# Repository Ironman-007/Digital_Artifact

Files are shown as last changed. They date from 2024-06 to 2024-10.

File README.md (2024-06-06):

# Digital_Artifact

Input devices:
- mouse encoder: https://www.amazon.com/gp/product/B0CF9FS3QS/ref=ppx_yo_dt_b_asin_title_o00_s00?ie=UTF8&psc=1
- thumb joystick: https://www.adafruit.com/product/5628
- thumbwheel:
  - https://www.mouser.com/ProductDetail/688-SLLB510100
  - https://www.digikey.com/en/products/detail/alps-alpine/RK10J11R0A0L/21721634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
- switch: https://www.amazon.com/TWTADE-Momentary-Assortment-Latching-QC-6X6MM/dp/B0858XRGYW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

MCU:
BC832

IMU:
ICM-20948 (9-DoF)

Actuator:
Linear vibrator

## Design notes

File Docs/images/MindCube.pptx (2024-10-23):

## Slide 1

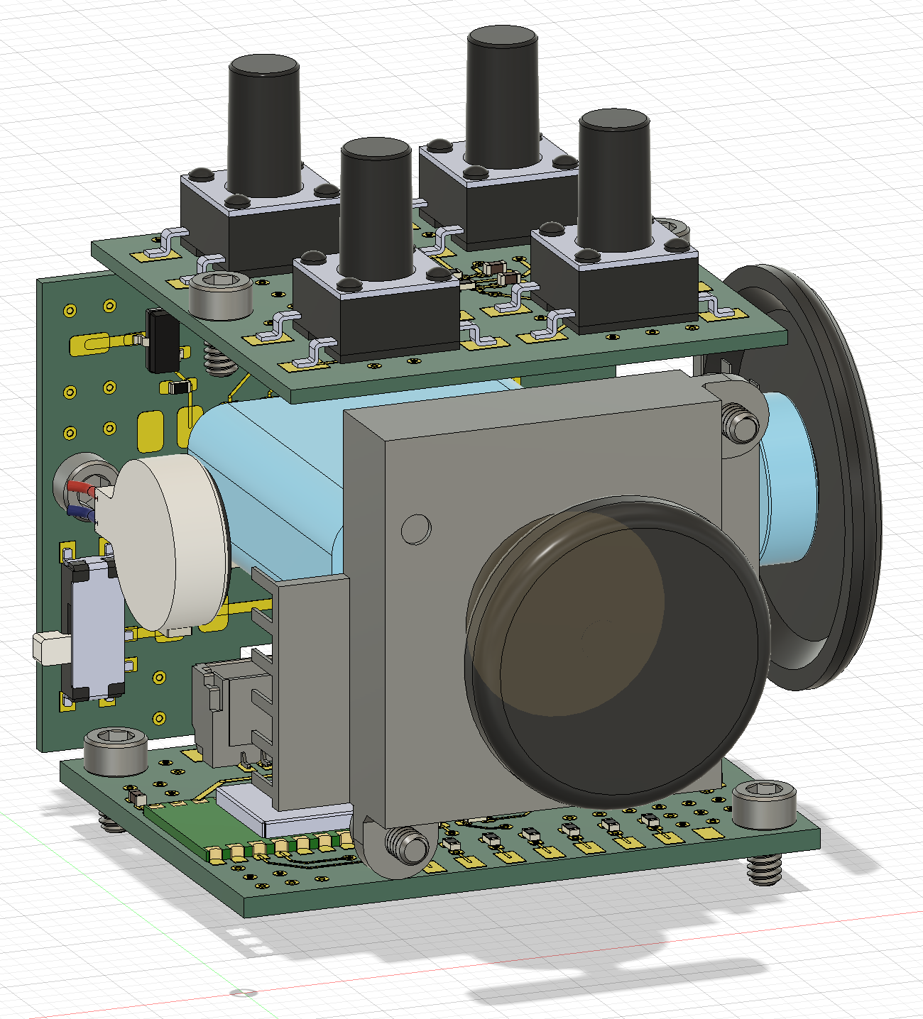
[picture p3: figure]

Button board

Connector board

Ball bearing

100mAh Li-Po

Linear vibration motor

TTC encoder

Joystick

33mm

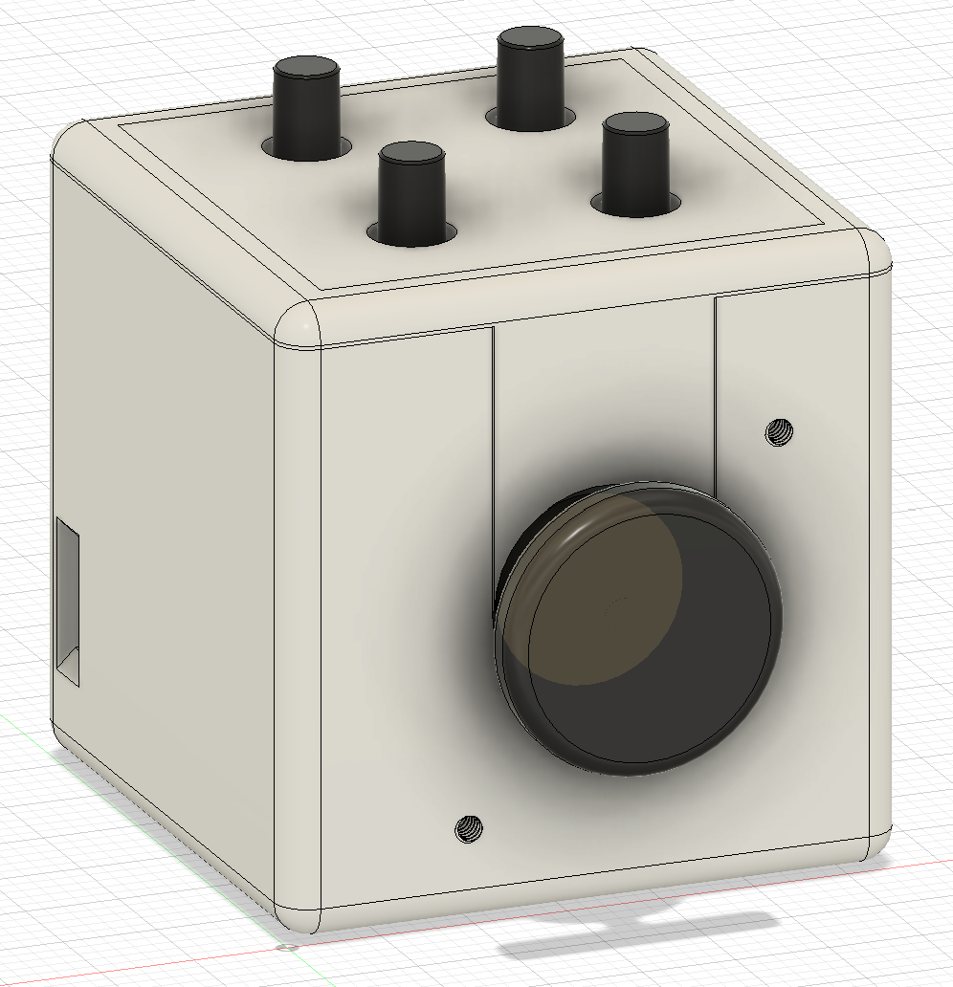
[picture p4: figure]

Main control board

33mm

33mm

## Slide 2

Main control board

Button board

Connector board

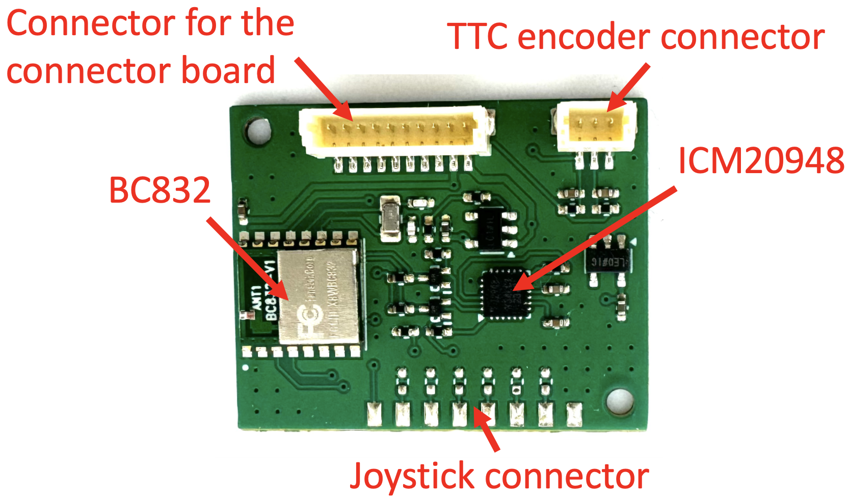
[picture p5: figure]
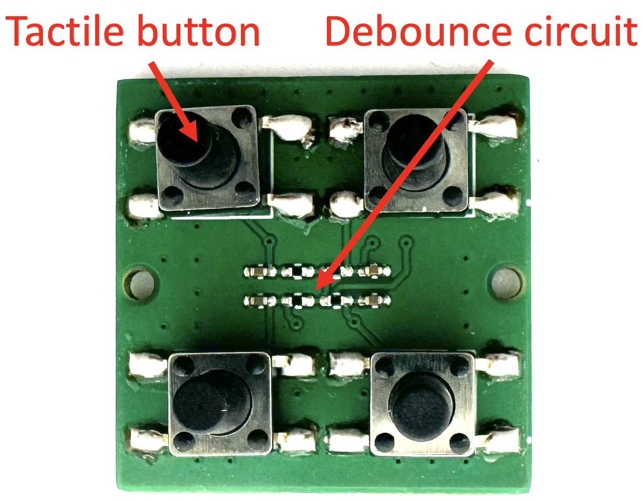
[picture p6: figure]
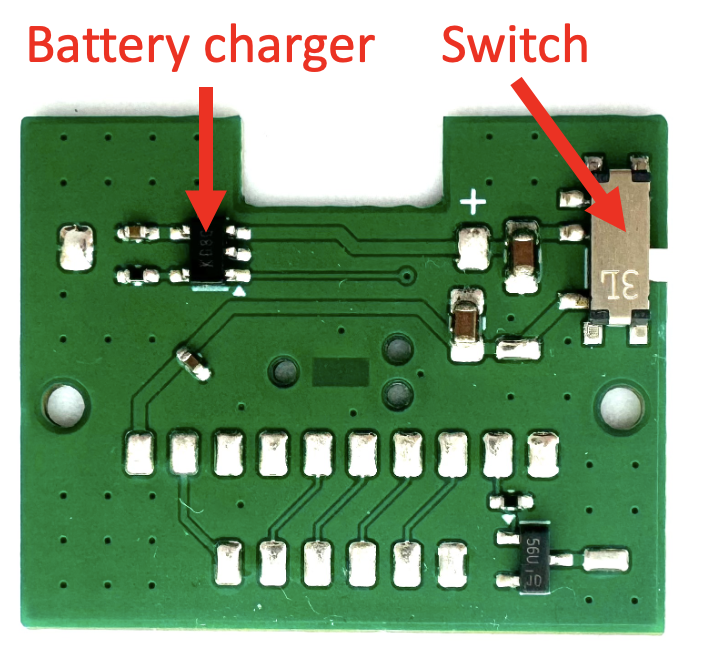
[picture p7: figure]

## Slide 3

Connector for the connector board

TTC encoder connector

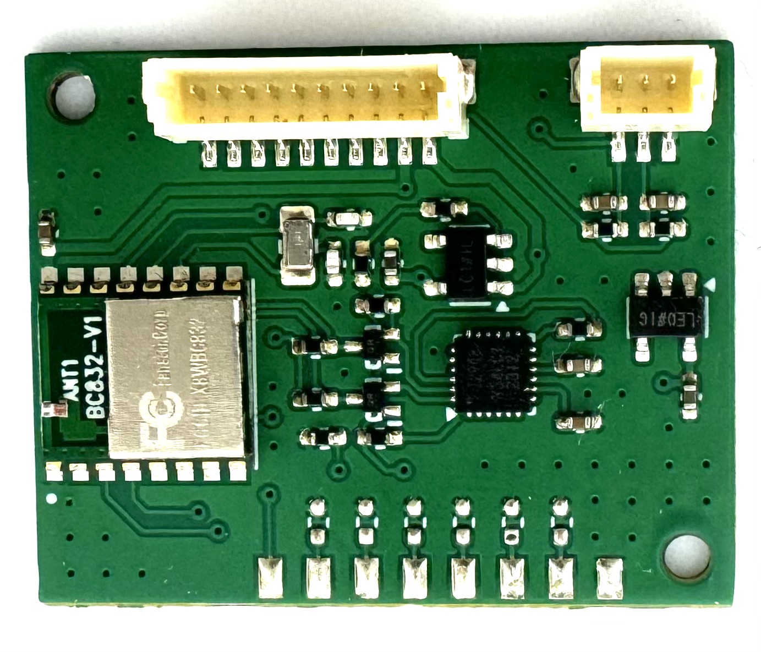
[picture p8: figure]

Joystick connector

ICM20948

BC832

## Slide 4

Tactile button

Debounce circuit

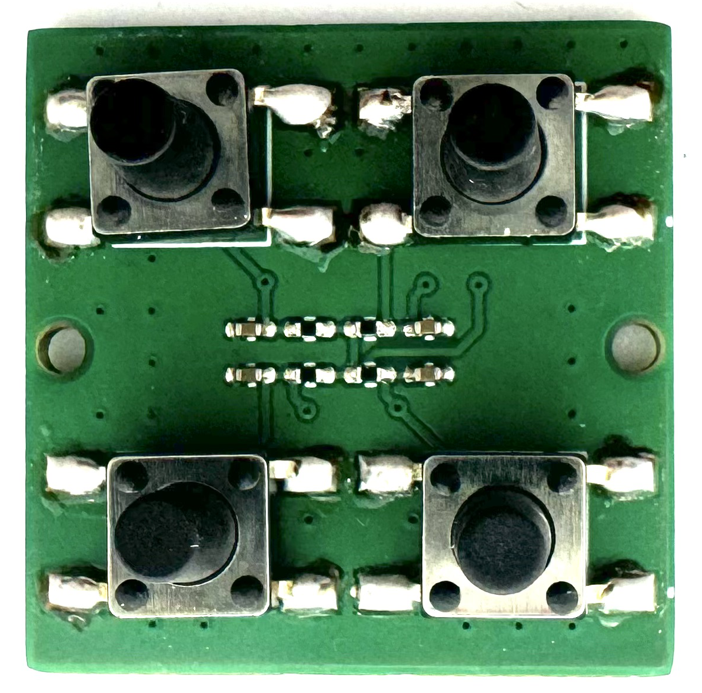
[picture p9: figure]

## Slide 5

Battery charger

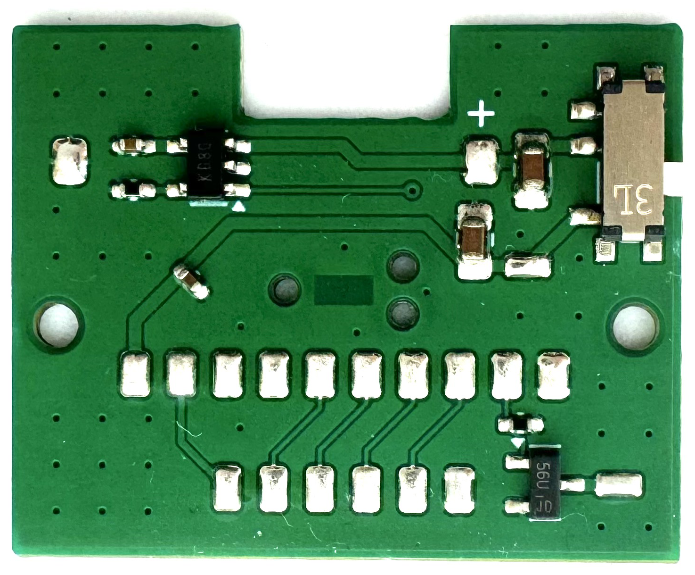
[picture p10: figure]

Switch

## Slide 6

Main control board

Joystick

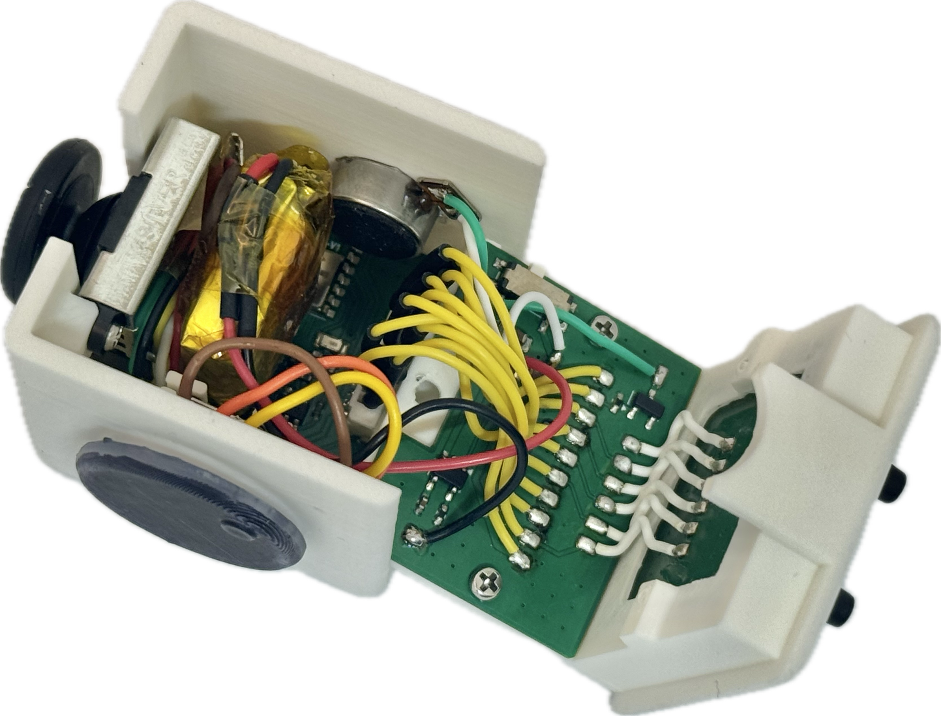
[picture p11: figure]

Linear vibration motor

Connector board

Button board

100mAh LiPo

TTC encoder

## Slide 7

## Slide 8

33mm

33mm

33mm

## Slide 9

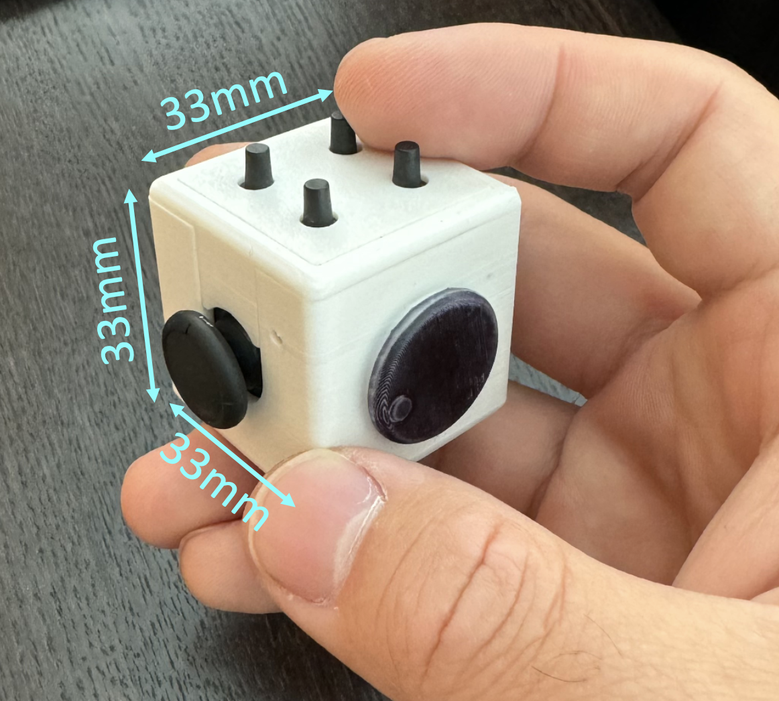
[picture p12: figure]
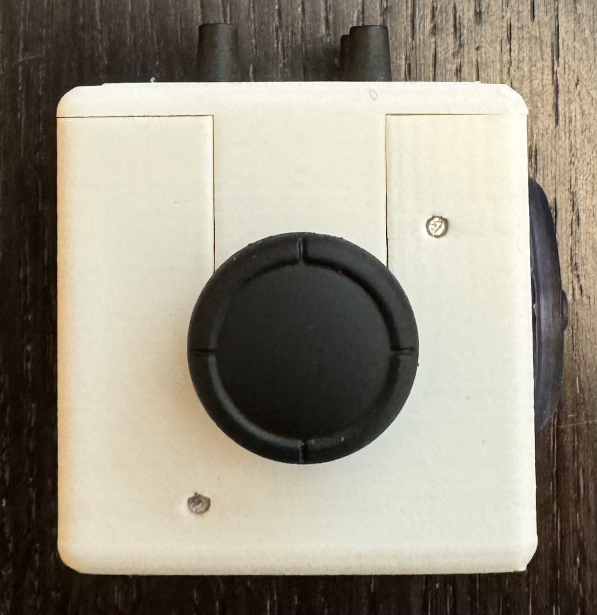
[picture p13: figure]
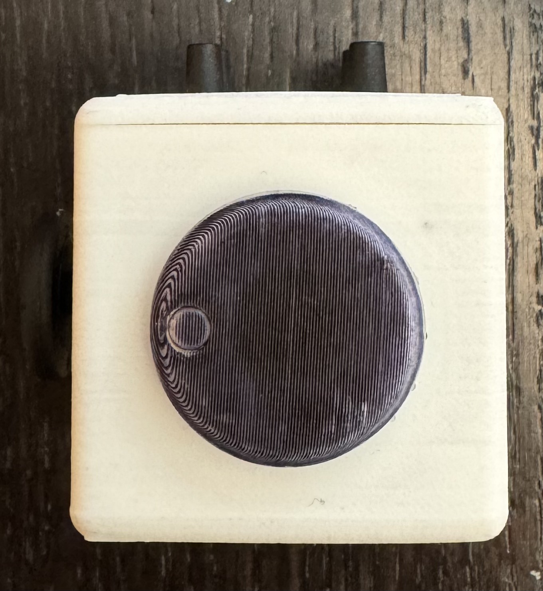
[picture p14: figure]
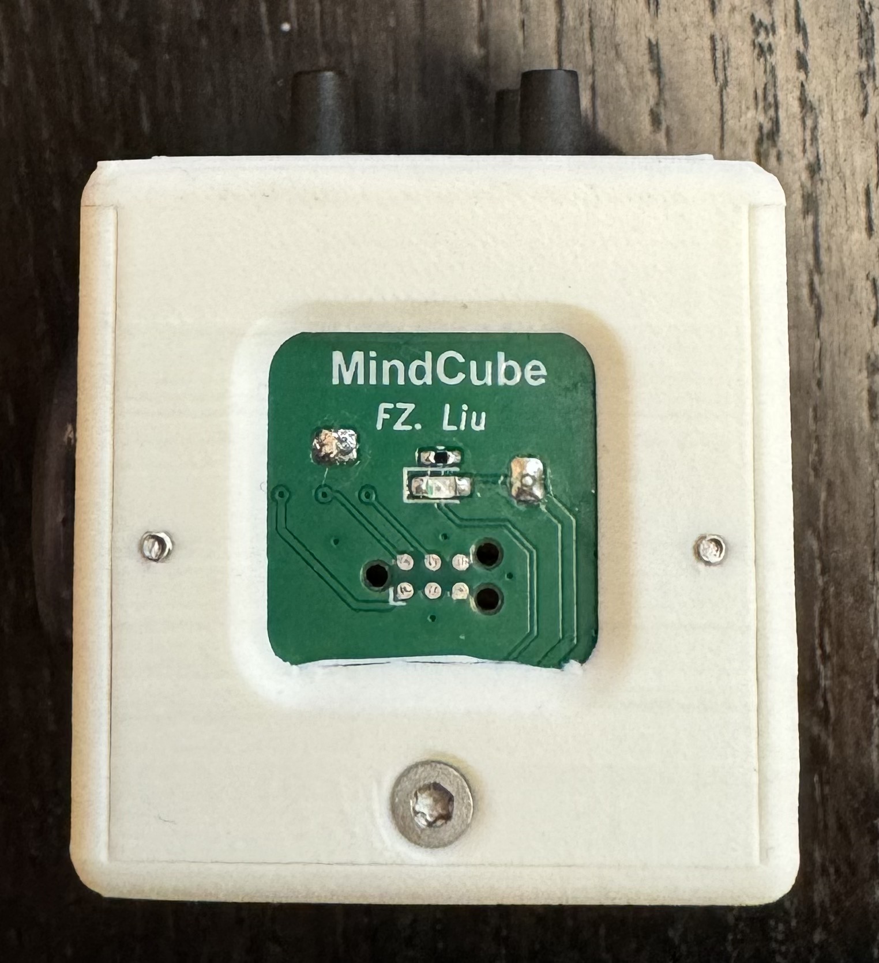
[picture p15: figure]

b

c

d

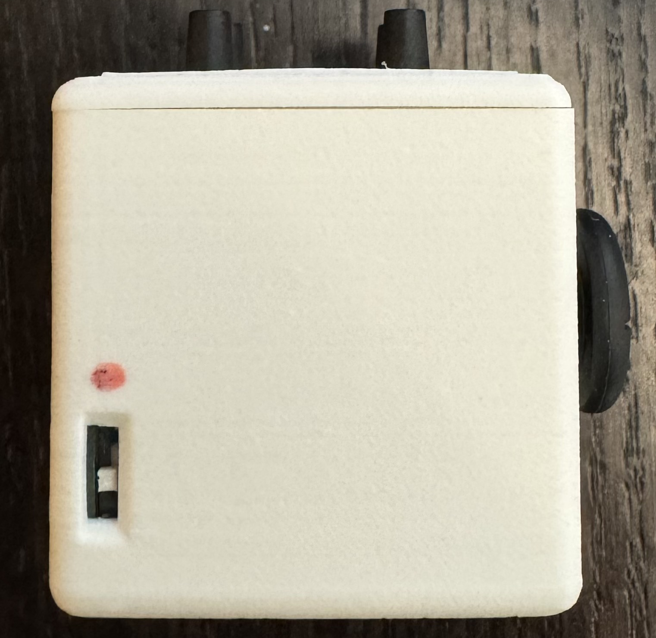
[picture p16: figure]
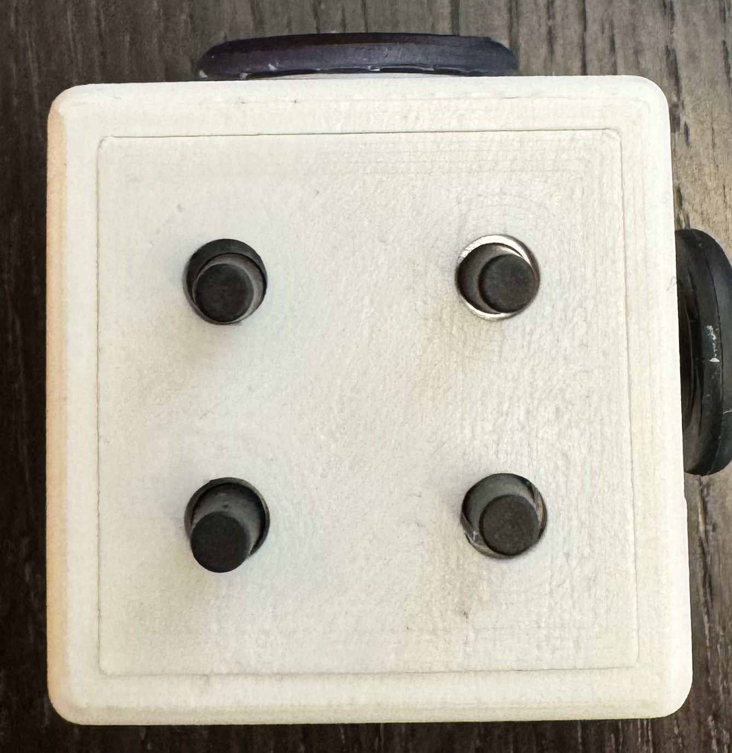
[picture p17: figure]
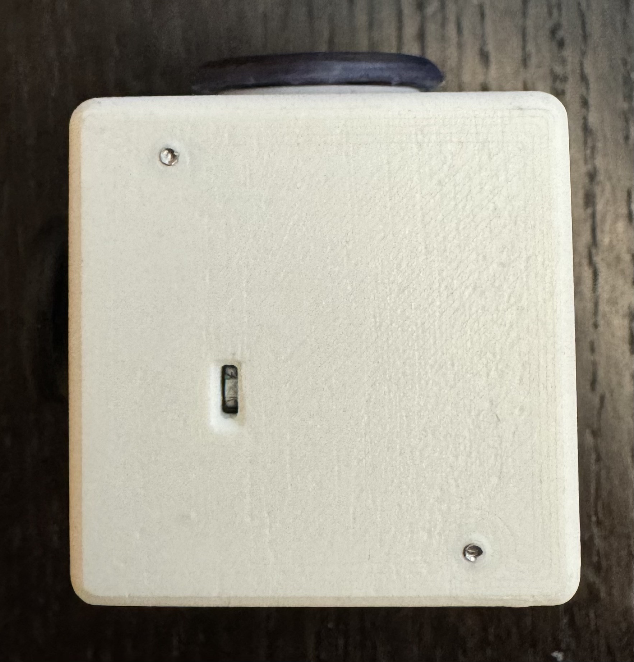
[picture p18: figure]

a

e

f

g

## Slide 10

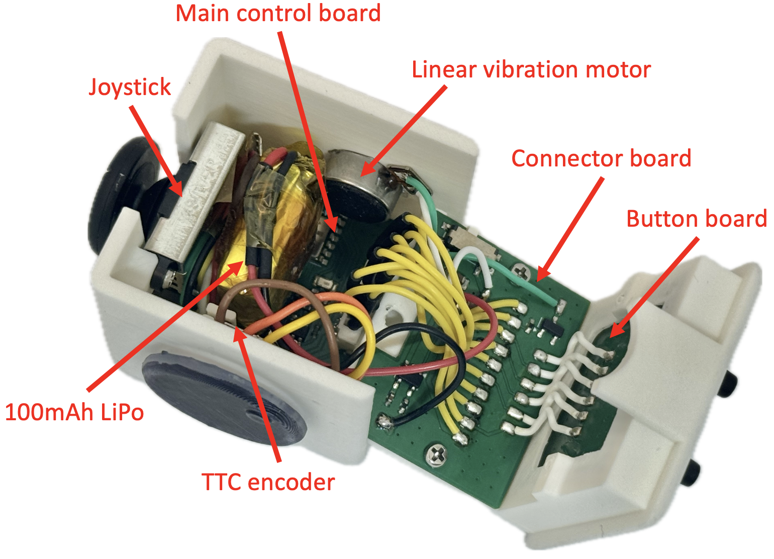
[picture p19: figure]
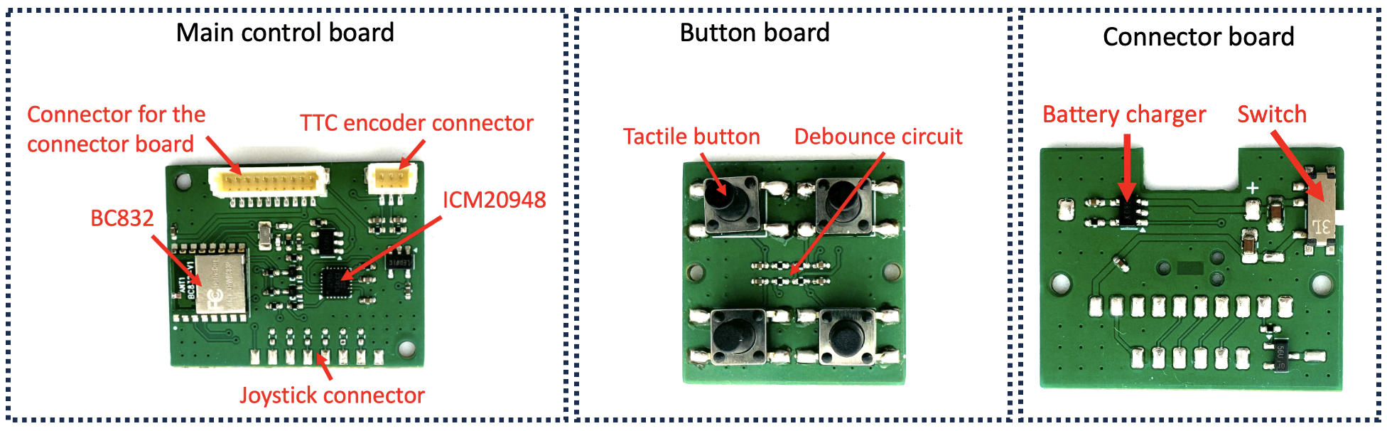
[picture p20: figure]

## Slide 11

Mapping

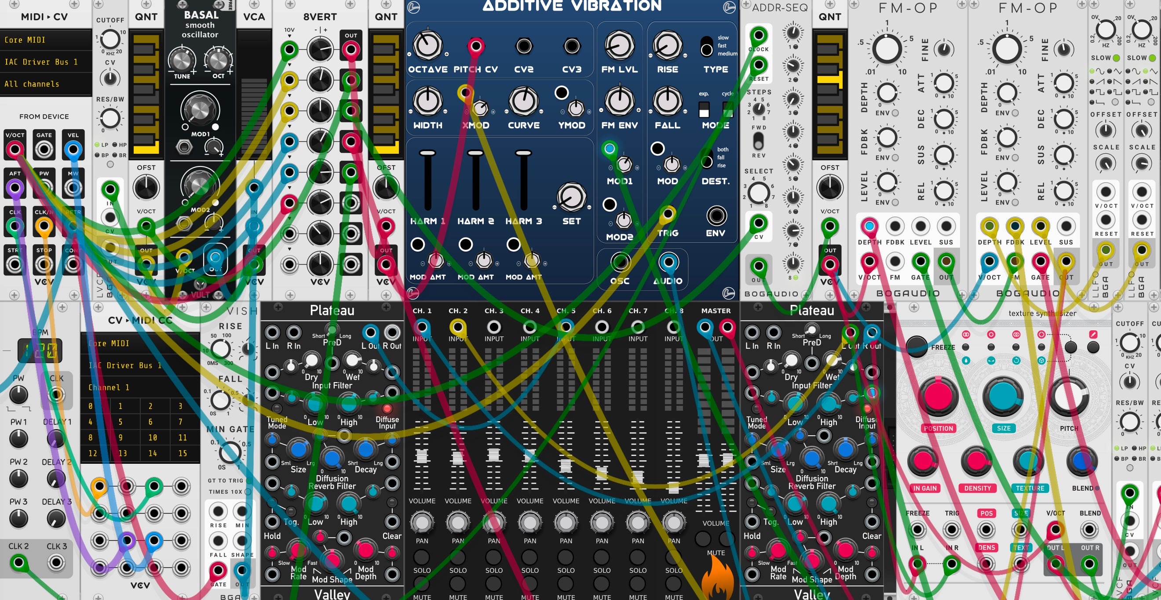
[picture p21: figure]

MIDI

Music

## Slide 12

Neural Network

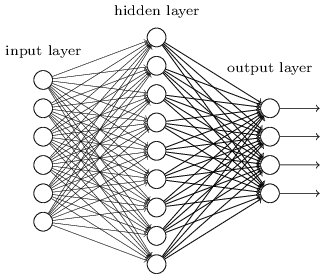
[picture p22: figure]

Focused?

Sensors data

Distracted?

Stressed?

…

Calm?

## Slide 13

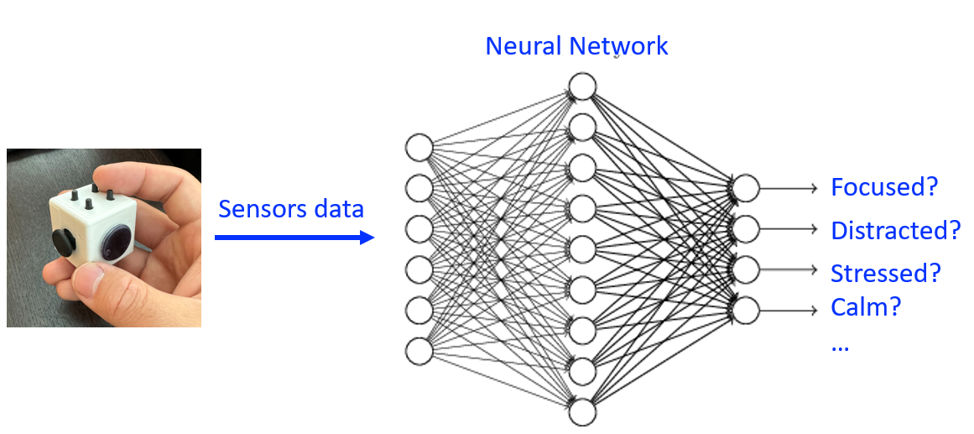
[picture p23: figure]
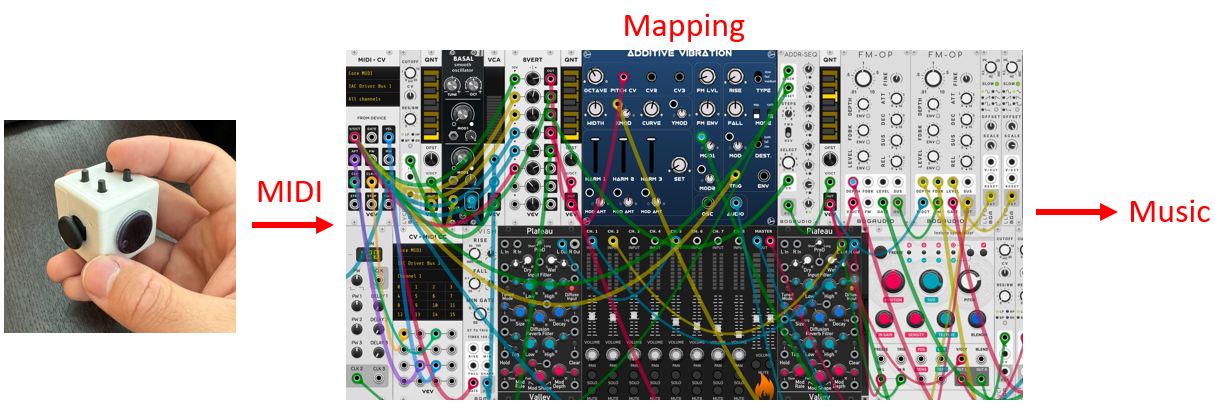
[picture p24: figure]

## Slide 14

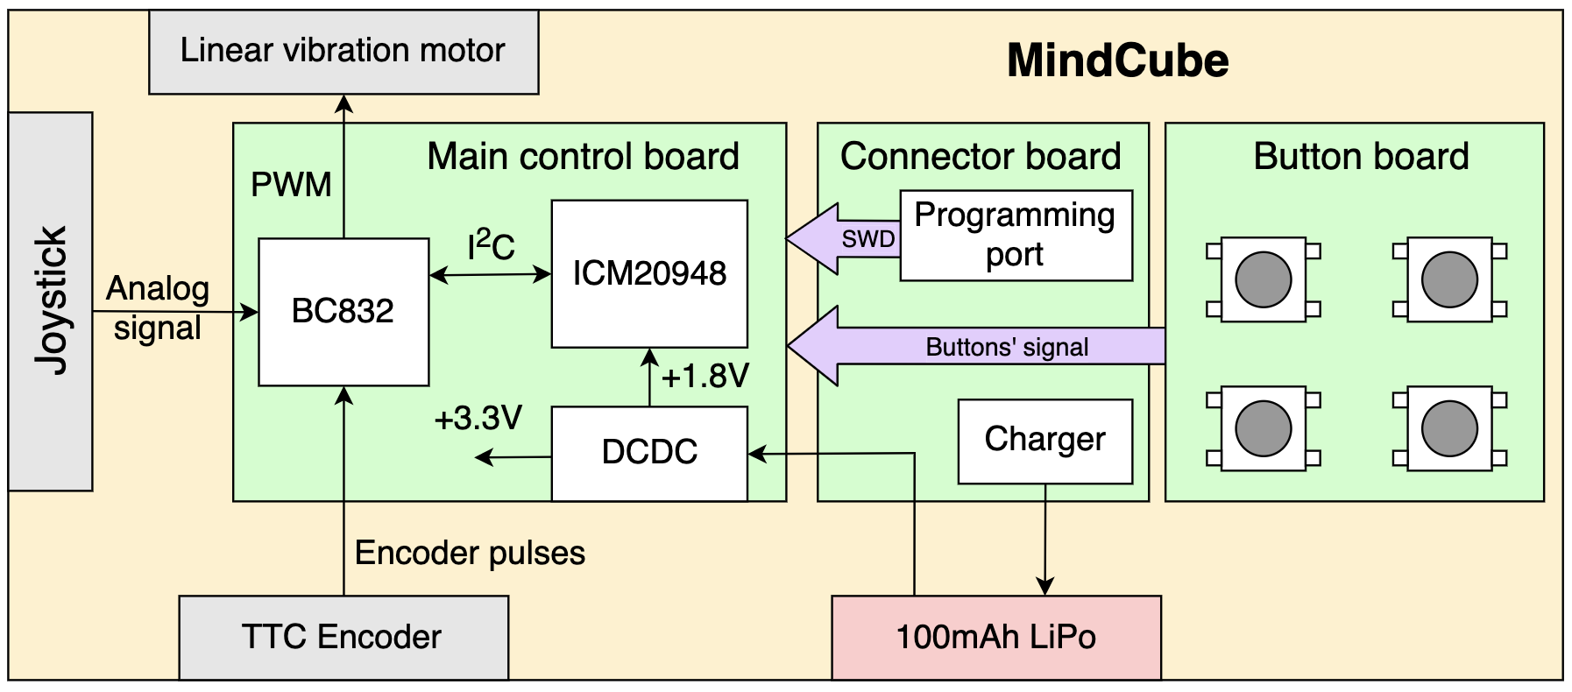
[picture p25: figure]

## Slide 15

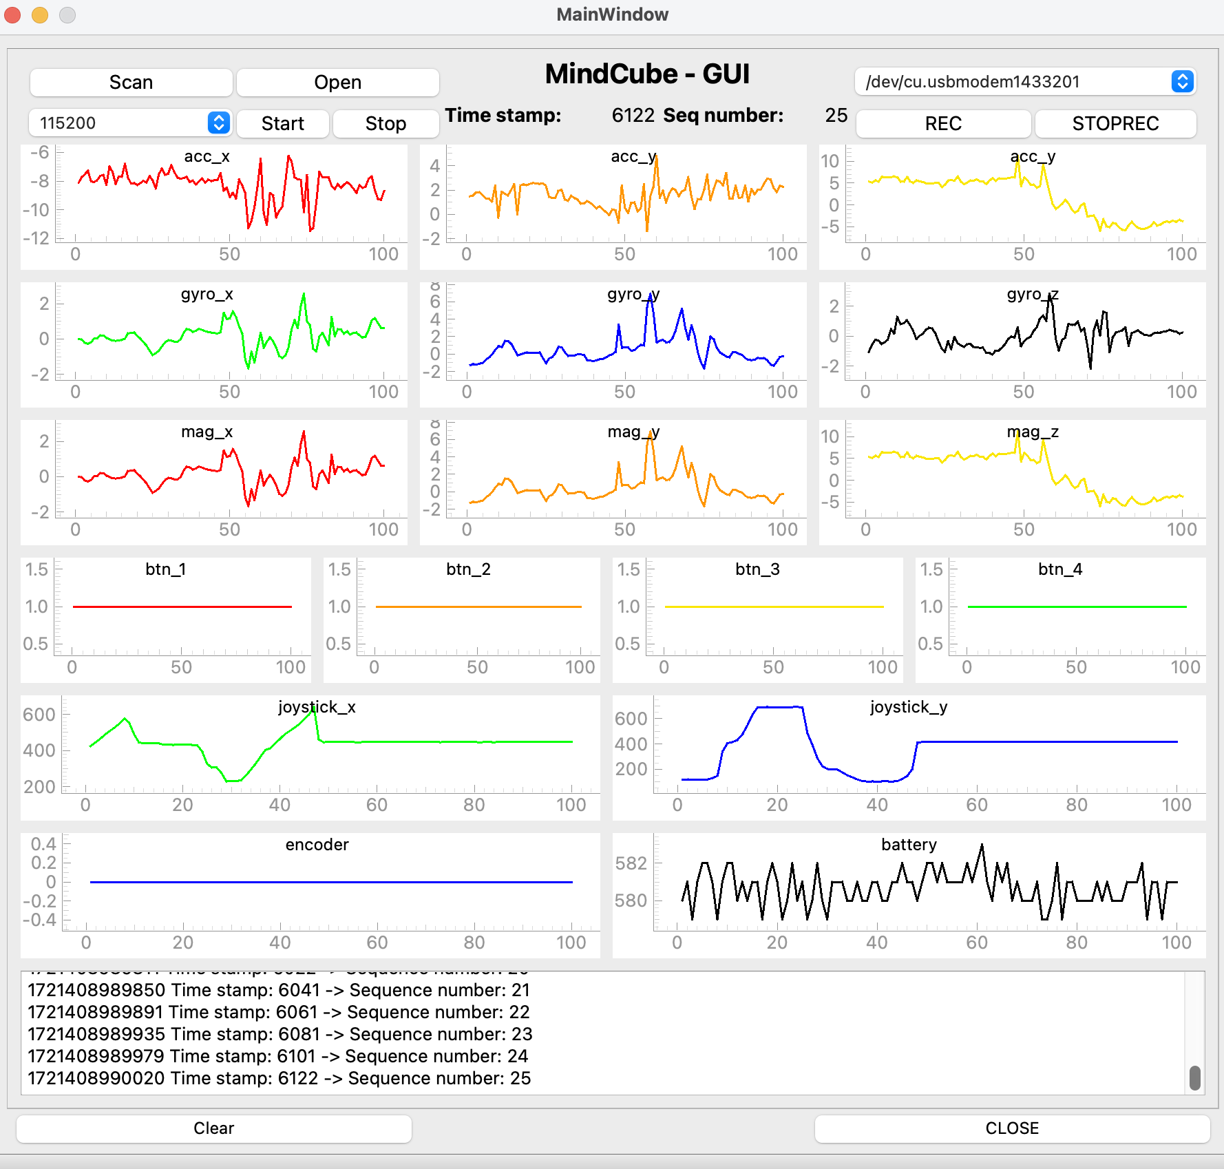
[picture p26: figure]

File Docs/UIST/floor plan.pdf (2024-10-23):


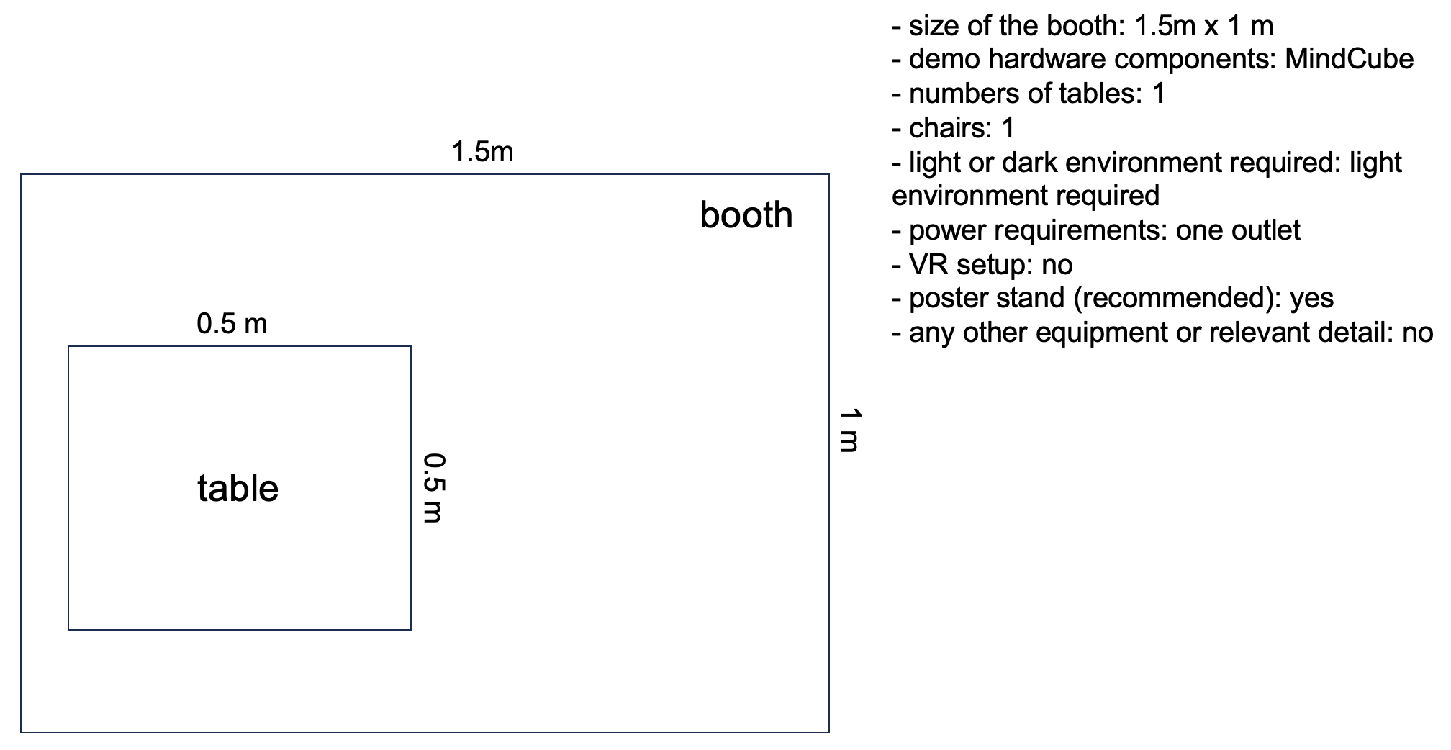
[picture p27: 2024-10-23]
Docs/images/floor plan.png

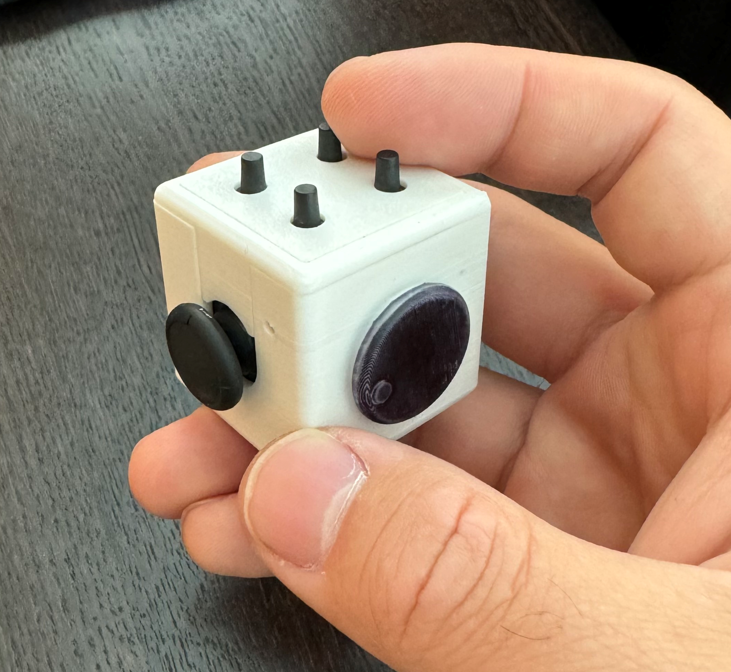
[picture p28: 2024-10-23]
Docs/images/cube.png

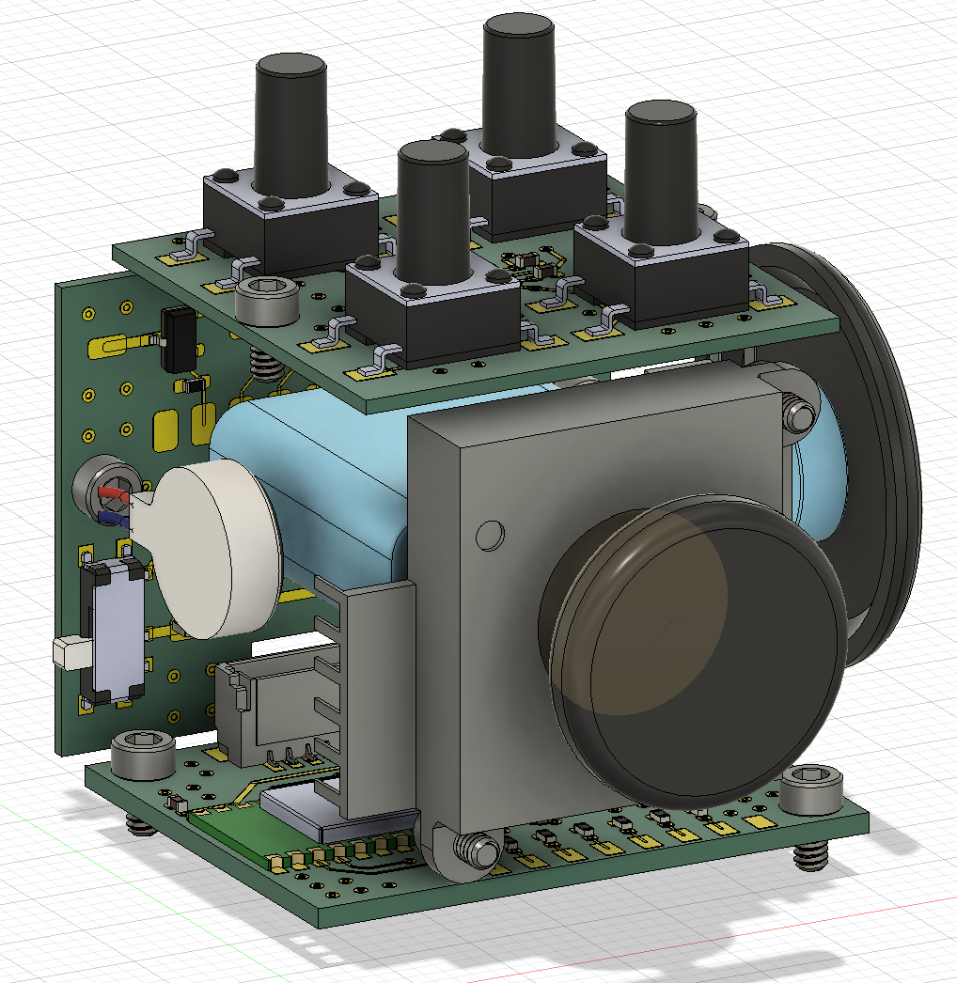
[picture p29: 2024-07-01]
Docs/images/internal.png

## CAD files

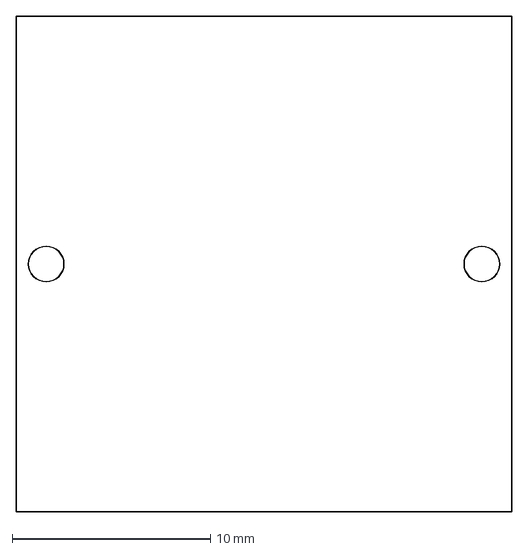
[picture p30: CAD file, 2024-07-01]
PCB/BTN/btn/btn_brd.dxf
25.0 x 25.0 mm

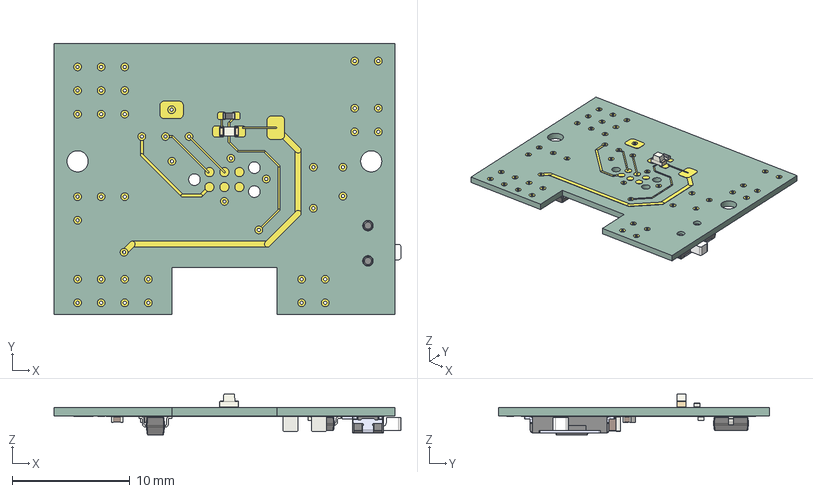
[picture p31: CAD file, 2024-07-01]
PCB/CONN/V1/CONN.step
29.4 x 23.0 x 3.45 mm
R_0402_1005Metric x 3
LED_0603_1608Metric
CUS-12TB
C_0402_1005Metric x 2
SOT_23
SOT_23_5
C_0805_2012Metric x 2
V1_track_1
V1_track_2
V1_track_3
V1_track_4
V1_track_5
V1_track_6
V1_track_7
V1_track_8
V1_track_9
V1_track_10
V1_track_11
V1_track_12
V1_track_13
V1_track_14
V1_track_15
V1_track_16
V1_track_17
V1_track_18
V1_track_19
V1_track_20
V1_track_21
V1_track_22
V1_track_23
V1_track_24
V1_track_25
V1_track_26
V1_track_27
V1_track_28
V1_track_29
V1_track_30
V1_track_31
V1_track_32
V1_track_33
V1_track_34
V1_track_35
V1_track_36
V1_track_37
V1_track_38
V1_track_39
V1_track_40
V1_track_41
V1_track_42
V1_track_43
V1_track_44
V1_track_45
V1_track_46
V1_track_47
V1_track_48
V1_track_49
V1_track_50
V1_track_51
V1_track_52
V1_track_53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

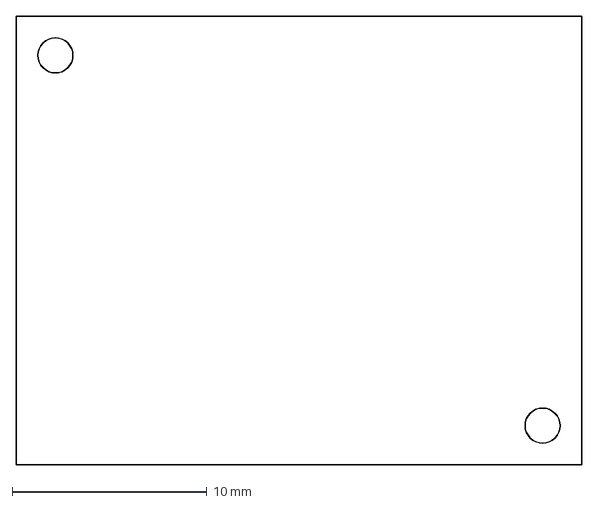
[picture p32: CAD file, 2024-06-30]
PCB/MCU/V1/MCU_board_outline.dxf
29.0 x 23.0 mm

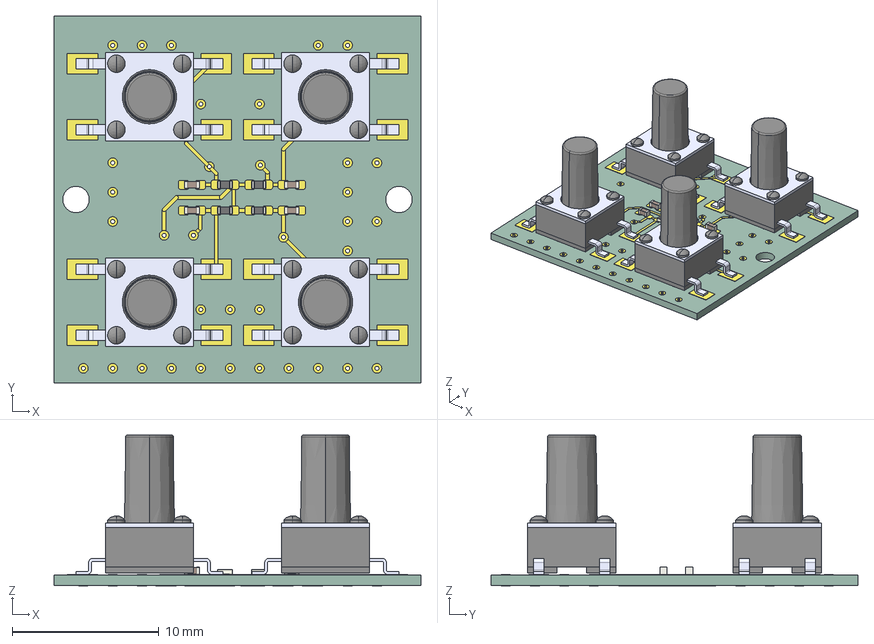
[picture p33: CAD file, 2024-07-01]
PCB/BTN/btn/btn.step
25.0 x 25.0 x 10.3 mm
C_0402_1005Metric x 4
TS04-66-95-BK-100-SMT x 4
R_0402_1005Metric x 4
btn_track_1
btn_track_2
btn_track_3
btn_track_4
btn_track_5
btn_track_6
btn_track_7
btn_track_8
btn_track_9
btn_track_10
btn_track_11
btn_track_12
btn_track_13
btn_track_14
btn_track_15
btn_track_16
btn_track_17
btn_track_18
btn_track_19
btn_track_20
btn_track_21
btn_track_22
btn_track_23
btn_track_24
btn_track_25
btn_track_26
btn_track_27
btn_track_28
btn_track_29
btn_track_30
btn_track_31
btn_track_32
btn_track_33
btn_track_34
btn_track_35
btn_pad_1
btn_pad_2
btn_pad_3
btn_pad_4
btn_pad_5
btn_pad_6
btn_pad_7
btn_pad_8
btn_pad_9
btn_pad_10
btn_pad_11
btn_pad_12
btn_pad_13
btn_pad_14
btn_pad_15
btn_pad_16
btn_pad_17
btn_pad_18
btn_pad_19
btn_pad_20
btn_pad_21
btn_pad_22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

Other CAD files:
PCB/CONN/V1/CONN.dxf

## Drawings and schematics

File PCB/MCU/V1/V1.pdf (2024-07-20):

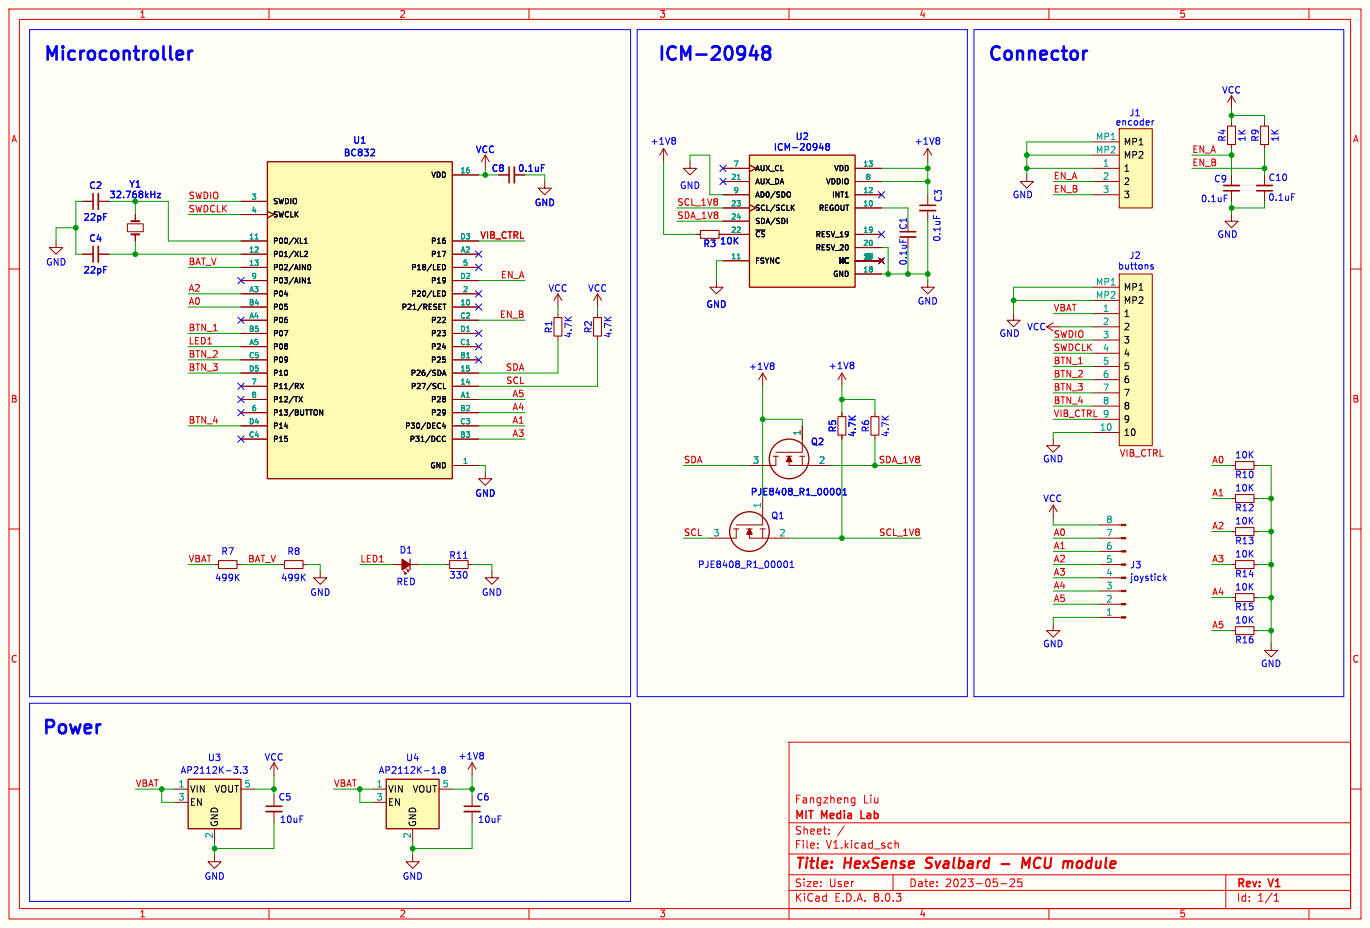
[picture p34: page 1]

Id: 1/1 Title: HexSense Svalbard - MCU module

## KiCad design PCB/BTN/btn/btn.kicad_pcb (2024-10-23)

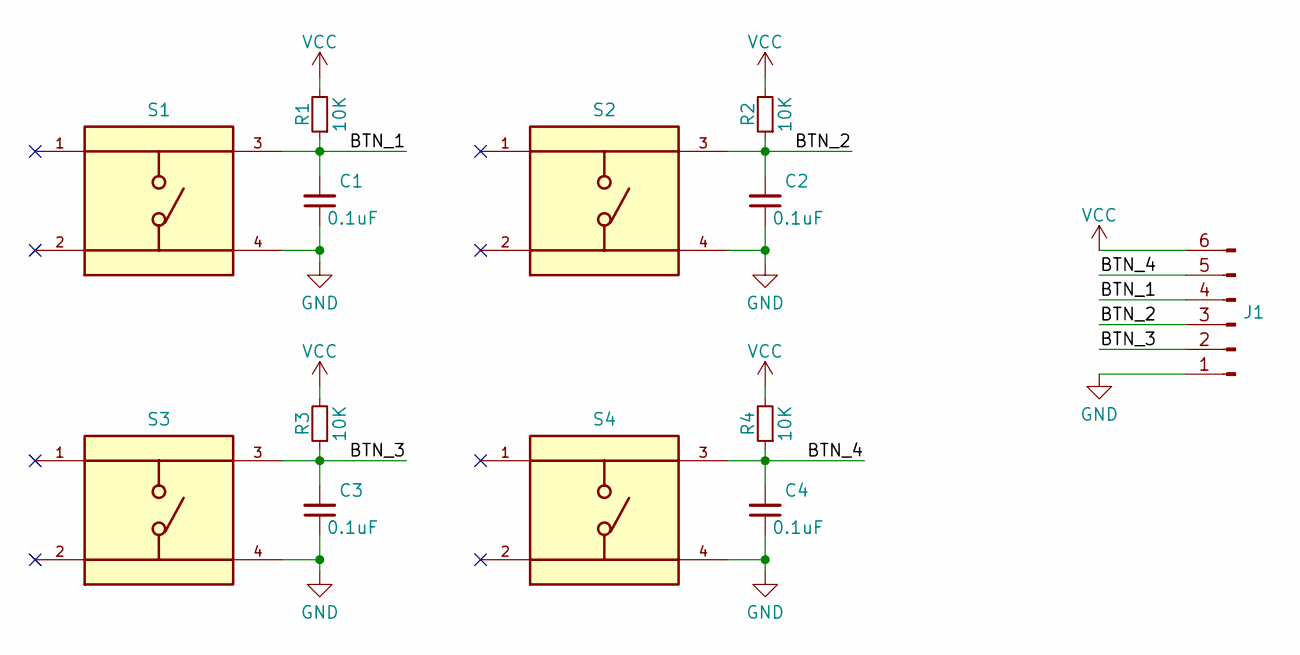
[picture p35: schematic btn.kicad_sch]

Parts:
C1, C2, C3, C4: 0.1uF; C_0402_1005Metric_Pad0.74x0.62mm_HandSolder
J1: Conn_01x06_Pin; Pinheader_2mmx6
R1, R2, R3, R4: 10K; R_0402_1005Metric_Pad0.72x0.64mm_HandSolder
S1, S2, S3, S4: TS04-66-95-BK-100-SMT; SW_TS04-66-95-BK-100-SMT; PARTREV 1.0

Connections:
/BTN_1: C1.2, J1.4, R1.1, S1.3
/BTN_2: C2.2, J1.3, R2.1, S2.3
/BTN_3: C3.2, J1.2, R3.1, S3.3
/BTN_4: C4.2, J1.5, R4.1, S4.3
GND: C1.1, C2.1, C3.1, C4.1, J1.1, S1.4, S2.4, S3.4, S4.4
VCC: J1.6, R1.2, R2.2, R3.2, R4.2

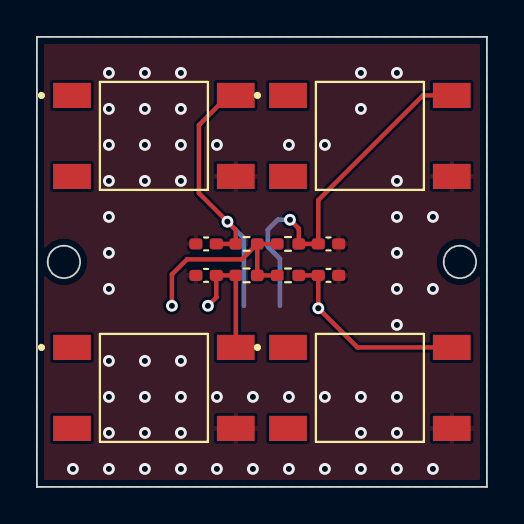
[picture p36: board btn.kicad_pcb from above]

Board: 2 copper layers, 25.0 x 25.0 mm, 13 parts (1 on the bottom side), 6 nets.

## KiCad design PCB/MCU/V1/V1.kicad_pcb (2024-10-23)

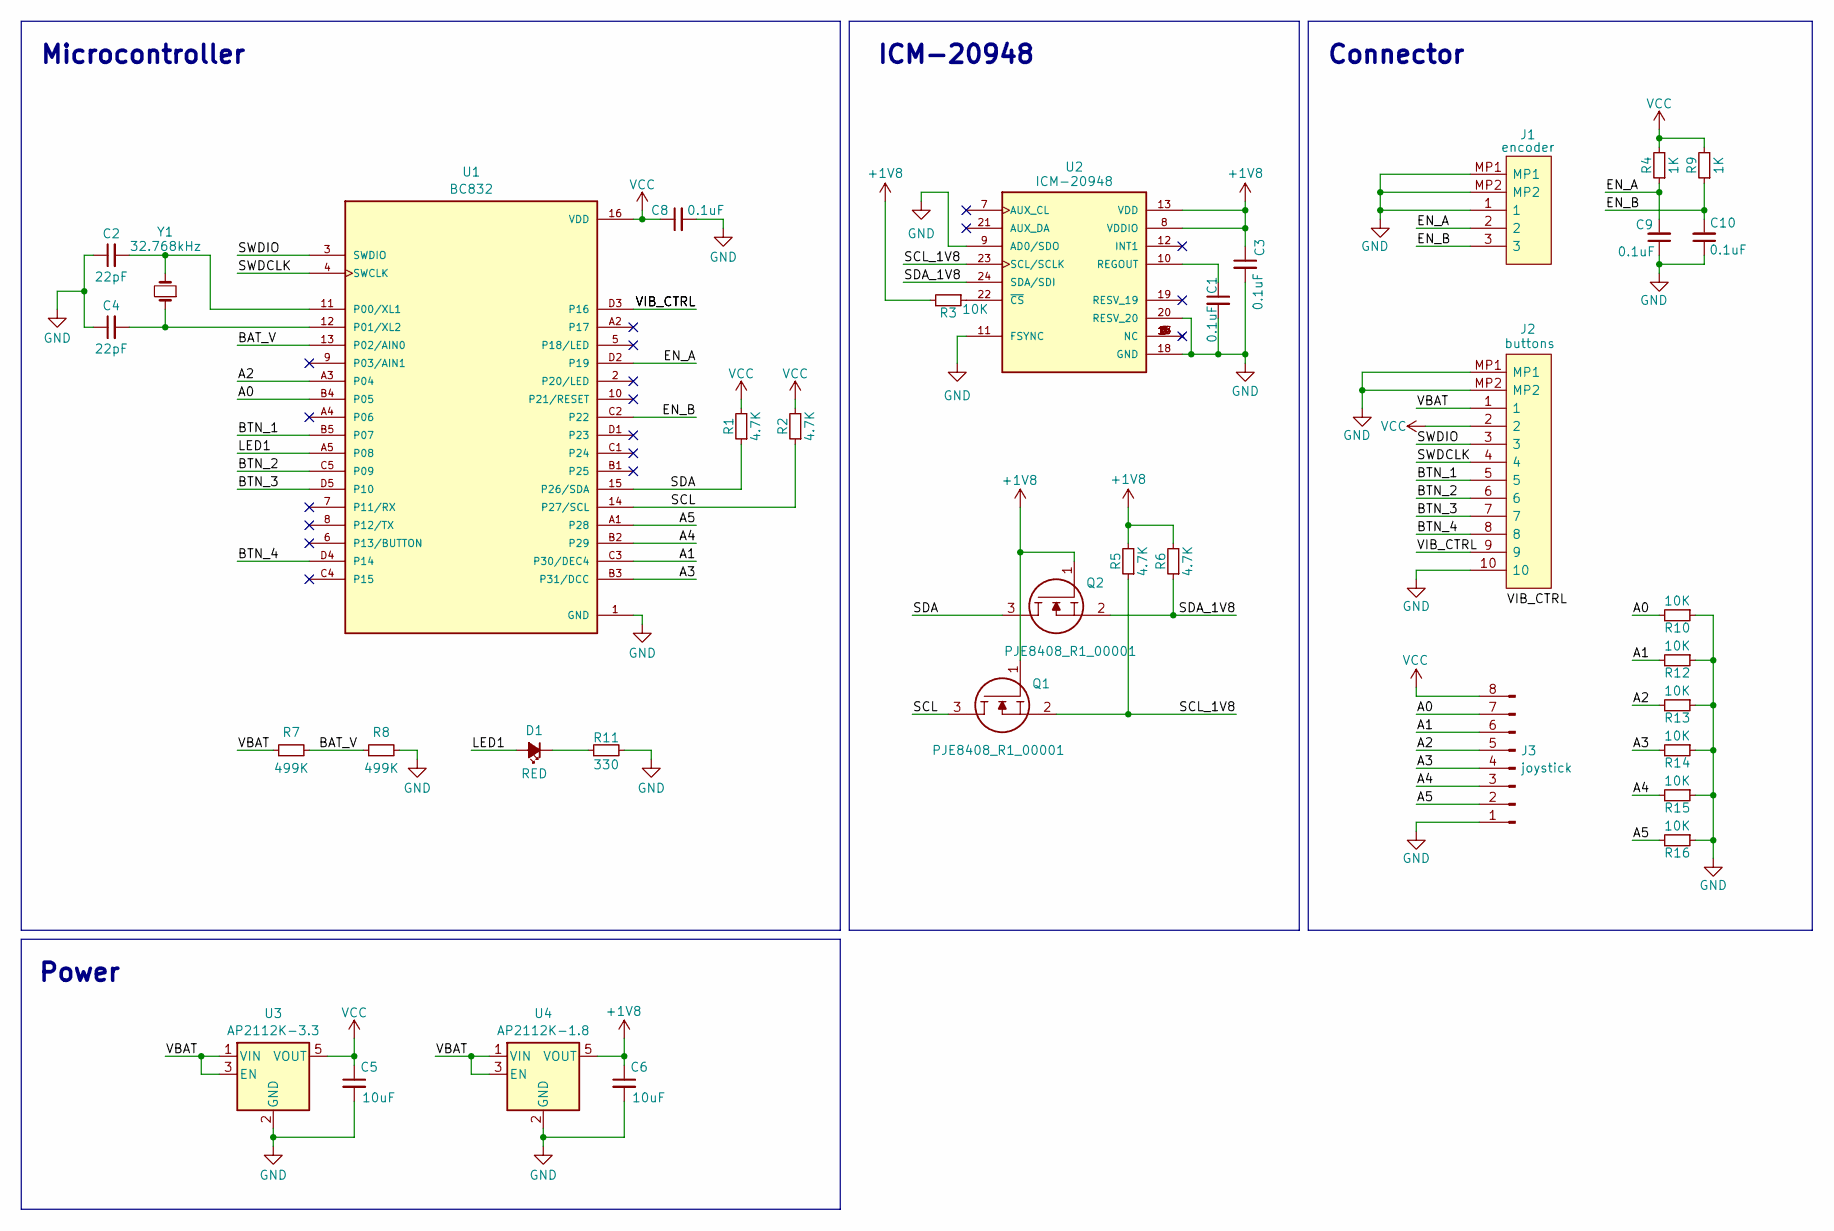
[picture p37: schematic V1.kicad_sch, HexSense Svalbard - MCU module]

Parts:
C1, C3, C8, C9, C10: 0.1uF; C_0402_1005Metric_Pad0.74x0.62mm_HandSolder
C2, C4: 22pF; C_0402_1005Metric_Pad0.74x0.62mm_HandSolder
C5, C6: 10uF; C_0402_1005Metric_Pad0.74x0.62mm_HandSolder
D1: RED; LED_0603_1608Metric_Pad1.05x0.95mm_HandSolder
J1: encoder; BM03BSRSSTBTLFSN; Manufacturer_Part_Number BM03B-SRSS-TBT(LF)(SN); Mouser Part Number N/A
J2: buttons; BM10BSRSSTBLFSN; Manufacturer_Part_Number BM10B-SRSS-TB (LF)(SN)
J3: joystick; pinheader_pitch_2mmx8
Q1, Q2: PJE8408_R1_00001; SOTFL50P160X60-3N; Manufacturer_Part_Number PJE8408_R1_00001; Mouser Part Number 241-PJE8408_R1_00001
R1, R2, R5, R6: 4.7K; R_0402_1005Metric_Pad0.72x0.64mm_HandSolder
R3, R10, R12, R13, R14, R15, R16: 10K; R_0402_1005Metric_Pad0.72x0.64mm_HandSolder
R4, R9: 1K; R_0402_1005Metric_Pad0.72x0.64mm_HandSolder
R7, R8: 499K; R_0402_1005Metric_Pad0.72x0.64mm_HandSolder
R11: 330; R_0402_1005Metric_Pad0.72x0.64mm_HandSolder
U1: BC832; XCVR_BC832
U2: ICM-20948; InvenSense_QFN-24_3x3mm_P0.4mm; PARTREV 1.3
U3: AP2112K-3.3; SOT-23-5
U4: AP2112K-1.8; SOT-23-5
Y1: 32.768kHz; C_0805_2012Metric_Pad1.18x1.45mm_HandSolder

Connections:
+1V8: C3.1, C6.1, Q1.1, Q2.1, R3.2, R5.2, R6.2, U2.8 (VDDIO), U2.13 (VDD), U4.5 (VOUT)
/A0: J3.7, R10.2, U1.B4 (P05)
/A1: J3.6, R12.2, U1.C3 (P30/DEC4)
/A2: J3.5, R13.2, U1.A3 (P04)
/A3: J3.4, R14.2, U1.B3 (P31/DCC)
/A4: J3.3, R15.2, U1.B2 (P29)
/A5: J3.2, R16.2, U1.A1 (P28)
/BAT_V: R7.2, R8.1, U1.13 (P02/AIN0)
/BTN_1: J2.5, U1.B5 (P07)
/BTN_2: J2.6, U1.C5 (P09)
/BTN_3: J2.7, U1.D5 (P10)
/BTN_4: J2.8, U1.D4 (P14)
/EN_A: C9.2, J1.2, R4.1, U1.D2 (P19)
/EN_B: C10.2, J1.3, R9.1, U1.C2 (P22)
/LED1: D1.2 (A), U1.A5 (P08)
/SCL: Q1.3, R2.1, U1.14 (P27/SCL)
/SCL_1V8: Q1.2, R5.1, U2.23 (SCL/SCLK)
/SDA: Q2.3, R1.1, U1.15 (P26/SDA)
/SDA_1V8: Q2.2, R6.1, U2.24 (SDA/SDI)
/SWDCLK: J2.4, U1.4 (SWCLK)
/SWDIO: J2.3, U1.3 (SWDIO)
/VBAT: J2.1, R7.1, U3.1 (VIN), U3.3 (EN), U4.1 (VIN), U4.3 (EN)
/VIB_CTRL: J2.9, U1.D3 (P16)
GND: C1.2, C2.1, C3.2, C4.1, C5.2, C6.2, C8.2, C9.1, C10.1, J1.1, J1.MP1, J1.MP2, J2.10, J2.MP1, J2.MP2, J3.1, R8.2, R10.1, R11.2, R12.1, R13.1, R14.1, R15.1, R16.1, U1.1 (GND), U2.9 (AD0/SDO), U2.11 (FSYNC), U2.18 (GND), U2.20 (RESV_20), U3.2 (GND), U4.2 (GND)
unnamed: D1.1 (K), R11.1
unnamed: C2.2, U1.11 (P00/XL1), Y1.2
unnamed: C4.2, U1.12 (P01/XL2), Y1.1
unnamed: C1.1, U2.10 (REGOUT)
unnamed: R3.1, U2.22 (~CS)
VCC: C5.1, C8.1, J2.2, J3.8, R1.2, R2.2, R4.2, R9.2, U1.16 (VDD), U3.5 (VOUT)

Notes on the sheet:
Microcontroller
ICM-20948
Power
Connector

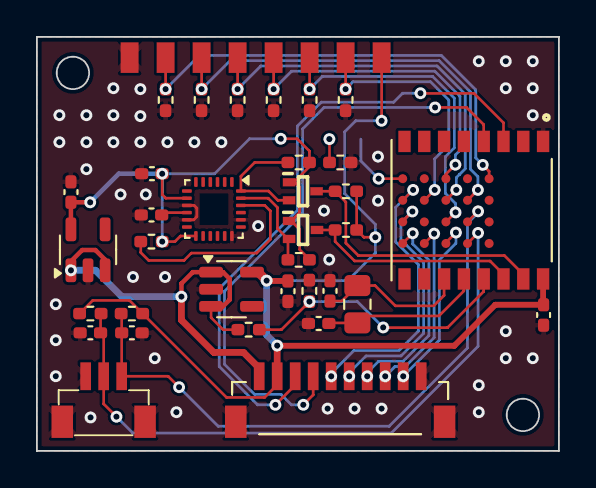
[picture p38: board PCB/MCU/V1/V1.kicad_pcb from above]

Board: 2 copper layers, 29.0 x 23.0 mm, 36 parts (1 on the bottom side), 30 nets.

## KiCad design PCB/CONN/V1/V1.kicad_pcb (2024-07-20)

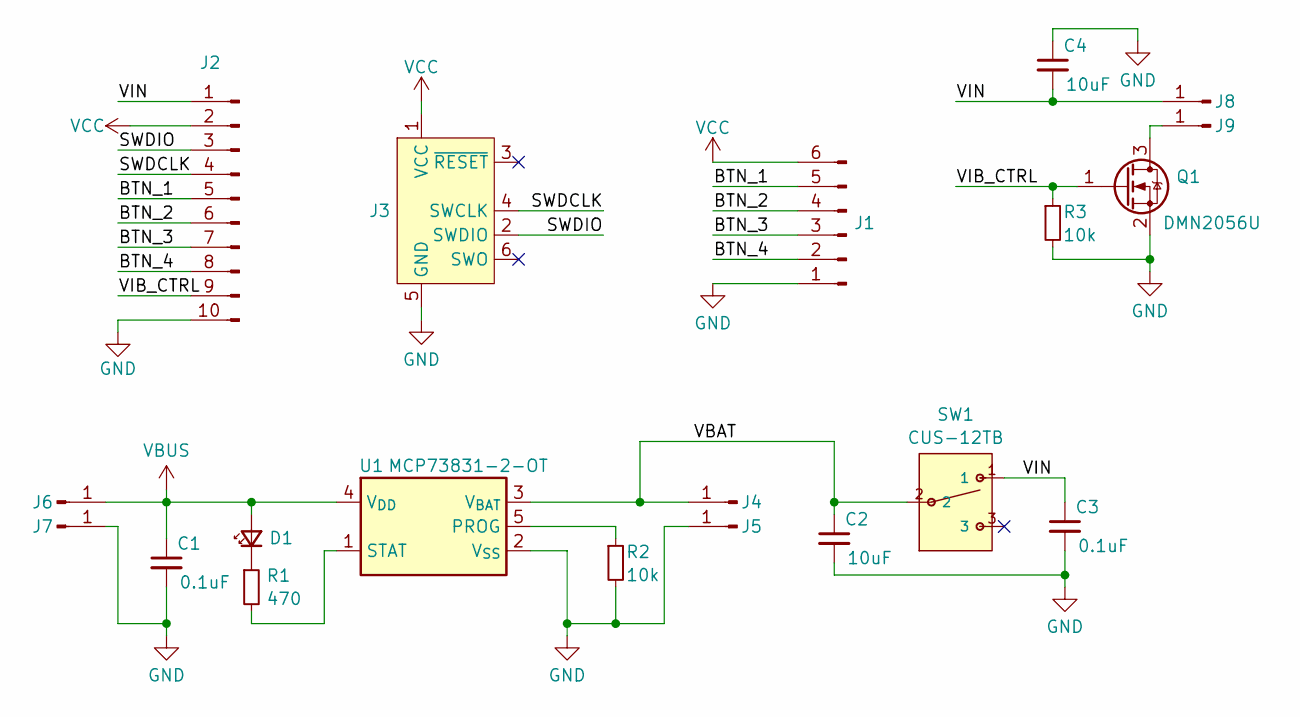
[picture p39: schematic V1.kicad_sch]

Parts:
C1, C3: 0.1uF; C_0402_1005Metric_Pad0.74x0.62mm_HandSolder
C2, C4: 10uF; C_0805_2012Metric_Pad1.18x1.45mm_HandSolder
D1: LED_Small; LED_0603_1608Metric_Pad1.05x0.95mm_HandSolder
J1: Conn_01x06_Pin; Pinheader_2mmx6
J2: Conn_01x10_Pin; Pinheader_2mmx10
J3: Conn_ARM_SWD_TagConnect_TC2030-NL; Tag-Connect_TC2030-IDC-NL_2x03_P1.27mm_Vertical
J4, J5, J6, J7, J8, J9: Conn_01x01_Pin; 1_pin
Q1: DMN2056U; SOT-23
R1: 470; R_0402_1005Metric_Pad0.72x0.64mm_HandSolder
R2, R3: 10k; R_0402_1005Metric_Pad0.72x0.64mm_HandSolder
SW1: CUS-12TB; CUS-12B; MANUFACTURER_PART_NUMBER CUS-12TB
U1: MCP73831-2-OT; SOT-23-5

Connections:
/BTN_1: J1.5, J2.5
/BTN_2: J1.4, J2.6
/BTN_3: J1.3, J2.7
/BTN_4: J1.2, J2.8
/SWDCLK: J2.4, J3.4 (SWCLK)
/SWDIO: J2.3, J3.2 (SWDIO)
/VBAT: C2.1, J4.1, SW1.2, U1.3 (V_{BAT})
/VIB_CTRL: J2.9, Q1.1 (G), R3.1
/VIN: C3.1, C4.2, J2.1, J8.1, SW1.1
GND: C1.2, C2.2, C3.2, C4.1, J1.1, J2.10, J3.5 (GND), J5.1, J7.1, Q1.2 (S), R2.2, R3.2, U1.2 (V_{SS})
unnamed: D1.1 (K), R1.1
unnamed: J9.1, Q1.3 (D)
unnamed: R2.1, U1.5 (PROG)
unnamed: R1.2, U1.1 (STAT)
VBUS: C1.1, D1.2 (A), J6.1, U1.4 (V_{DD})
VCC: J1.6, J2.2, J3.1 (VCC)

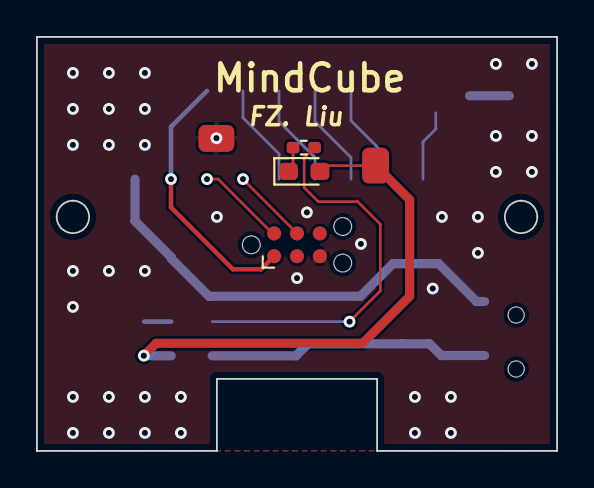
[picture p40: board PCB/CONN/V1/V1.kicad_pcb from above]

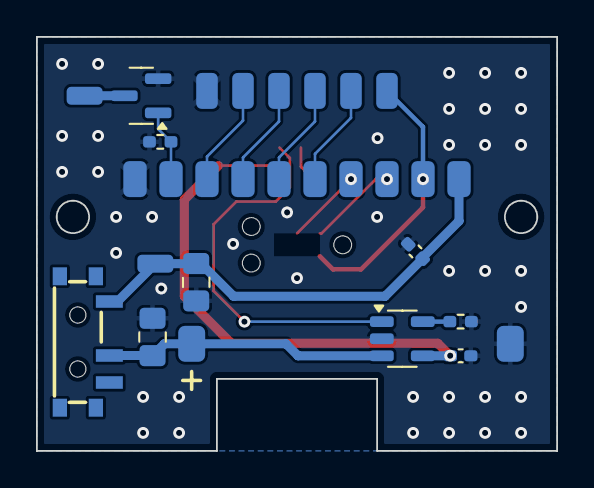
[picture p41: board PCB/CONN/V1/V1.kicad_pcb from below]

Board: 2 copper layers, 28.9 x 23.0 mm, 20 parts (15 on the bottom side), 16 nets.

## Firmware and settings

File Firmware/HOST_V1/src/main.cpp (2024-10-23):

#include <Arduino.h>
#include <bluefruit.h>

BLEClientUart clientUart; // bleuart client

/**
 * Callback invoked when scanner pick up an advertising data
 * @param report Structural advertising data
 */
void scan_callback(ble_gap_evt_adv_report_t* report)
{
  // Check if advertising contain BleUart service
  if ( Bluefruit.Scanner.checkReportForService(report, clientUart) )
  {
    // Connect to device with bleuart service in advertising
    Bluefruit.Central.connect(report);
  }else
  {      
    // For Softdevice v6: after received a report, scanner will be paused
    // We need to call Scanner resume() to continue scanning
    Bluefruit.Scanner.resume();
  }
}

/**
 * Callback invoked when an connection is established
 * @param conn_handle
 */
void connect_callback(uint16_t conn_handle)
{
  if ( clientUart.discover(conn_handle) )
  {
    clientUart.enableTXD();
  } else
  {
    // disconnect since we couldn't find bleuart service
    Bluefruit.disconnect(conn_handle);
  }  
}

/**
 * Callback invoked when a connection is dropped
 * @param conn_handle
 * @param reason is a BLE_HCI_STATUS_CODE which can be found in ble_hci.h
 */
void disconnect_callback(uint16_t conn_handle, uint8_t reason)
{
  (void) conn_handle;
  (void) reason;
}

/**
 * Callback invoked when uart received data
 * @param uart_svc Reference object to the service where the data 
 * arrived. In this example it is clientUart
 */
void bleuart_rx_callback(BLEClientUart& uart_svc)
{
  while ( uart_svc.available() )
  {
    Serial.write(uart_svc.read());
  }
}

void setup()
{
  Serial.begin(115200);
 while ( !Serial ) delay(10);   // for nrf52840 with native usb

  // Initialize Bluefruit with maximum connections as Peripheral = 0, Central = 1
  // SRAM usage required by SoftDevice will increase dramatically with number of connections
  Bluefruit.begin(0, 1);
  
  Bluefruit.setName("MindCube Central");

  // Init BLE Central Uart Serivce
  clientUart.begin();
  clientUart.setRxCallback(bleuart_rx_callback);

  // Increase Blink rate to different from PrPh advertising mode
  Bluefruit.setConnLedInterval(250);

  // Callbacks for Central
  Bluefruit.Central.setConnectCallback(connect_callback);
  Bluefruit.Central.setDisconnectCallback(disconnect_callback);

  /* Start Central Scanning
   * - Enable auto scan if disconnected
   * - Interval = 100 ms, window = 80 ms
   * - Don't use active scan
   * - Start(timeout) with timeout = 0 will scan forever (until connected)
   */
  Bluefruit.Scanner.setRxCallback(scan_callback);
  Bluefruit.Scanner.restartOnDisconnect(true);
  Bluefruit.Scanner.setInterval(160, 80); // in unit of 0.625 ms
  Bluefruit.Scanner.useActiveScan(false);
  Bluefruit.Scanner.start(0);                   // // 0 = Don't stop scanning after n seconds
}

void loop()
{
  if ( Bluefruit.Central.connected() )
  {
    // Not discovered yet
    if ( clientUart.discovered() )
    {
      ; // do nothing
    }
  }
}

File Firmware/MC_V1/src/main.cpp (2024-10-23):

#include "MC_system_FZ.h"
#include "MC_joystick_FZ.h"
#include "MC_IMU_FZ.h"
#include "MC_comm_FZ.h"
#include "MC_btn_FZ.h"
#include "MC_encoder_FZ.h"

void setup() {
  MC_systemInit();
  MC_joystickInit();
  MC_btn_init();
  MC_encoder_init();
  MC_imu_init();
  MC_BLE_init();
  MC_BLE_startAdv();

  MC_interrupt_init();

  MC_flash_led(LED_PIN, 10);
}

void loop() {
  if (ble_connnected) {
    if (timer4Interrupt_2ms) {
      timer4Interrupt_2ms = false;

      MC_read_encoder();
    }

    if (timer4Interrupt_20ms) {
      timer4Interrupt_20ms = false;

      MC_joystickRead();
      MC_read_imu();
      MC_read_btn();
      MC_read_bat_v();

      MC_pack_ack();
      MC_comm_send_data();
    }
  }
}

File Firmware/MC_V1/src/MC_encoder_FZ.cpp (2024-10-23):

#include "MC_encoder_FZ.h"

int lastStateCLK    = 0;
int currentStateCLK = 0;

long encoder_count  = 0;

void MC_encoder_init() {
  pinMode(ENCODER_1_PIN, INPUT);
  pinMode(ENCODER_2_PIN, INPUT);
}

void MC_read_encoder(void) {
  currentStateCLK = digitalRead(ENCODER_1_PIN);

  if (currentStateCLK != lastStateCLK  && currentStateCLK == 1) {
    if (digitalRead(ENCODER_2_PIN) != currentStateCLK) {
      encoder_count --;
    } else {
      encoder_count ++;
    }
  }

  // Remember last CLK state
  lastStateCLK = currentStateCLK;
}

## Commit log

2024-04-14 udated by FZ
    [V1.kicad_pcb, V1.kicad_sch]
2024-07-14 blink LED working
2024-07-17 BLE all except encoder working
2024-07-17 added encoder but seems not working yet
    [MC_comm_FZ.cpp, MC_encoder_FZ.cpp, MC_system_FZ.cpp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]
2024-07-18 Encoder seems working but only one direction
2024-07-18 Encoder seems working now, lower the sample rate to 200Hz
